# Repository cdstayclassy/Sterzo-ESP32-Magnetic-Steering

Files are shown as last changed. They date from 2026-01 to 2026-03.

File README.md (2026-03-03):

# Build your own bike trainer steering device with an ESP32 and AS5600 magnetic sensor!

A DIY bike trainer for apps such as Zwift or GTBikeV, similar to the Sterzo steering device. This project, built using an ESP32 and AS5600 magnetic rotary position sensor using the Sterzo protocol, allows you to add realistic steering control to your indoor cycling experience using a rotating handlebar mechanism with magnetic angle detection.

## Features

- Smooth, continuous steering control using magnetic rotary position sensor
- Bluetooth Low Energy (BLE) communication with Zwift and GTBikeV
- Auto-calibration at startup
- Handlebar-mounted recenter button for mid-ride calibration
- ±40° steering range (Zwift standard)
- Configurable dead zone for easier straight-line riding
- Adjustable sensitivity and update rate
- LED status indicator with error codes for easy troubleshooting
- All settings easily configurable at top of code file
- **Steering Overlay** — floating Python app showing live angle via BLE or USB serial

## Hardware Required

**Required:**
- **ESP32 Development Board** (any variant with I2C support)
- **AS5600 Magnetic Rotary Position Sensor** - 12-bit contactless angle measurement
- **Diametrically magnetized magnet** (typically included with AS5600 or purchase separately)
  - Recommended: 6mm diameter x 3mm thickness
- **Mounting mechanism** for handlebar rotation (DIY - see below)
- **Jumper wires** - for connections
- **USB cable** - for power and programming

**Optional:**
- **3-5mm LED and 220Ω resistor** (any color) - for status indication
- **Momentary push button** - for recenter function

## Wiring Connections

### AS5600 Sensor

| AS5600 Pin | ESP32 Pin | Description |
|---|---|---|
| VCC | 3.3V | Power supply (use 3.3V, NOT 5V) |
| GND | GND | Ground |
| SDA | GPIO 21 | I2C Data |
| SCL | GPIO 20 | I2C Clock (compatible with ESP32 Mini) |

### External LED - OPTIONAL (Status Indicator)

| LED Connection | ESP32 Pin | Description |
|---|---|---|
| LED Anode (+, long leg) | GPIO 2 | Via 220Ω resistor |
| LED Cathode (-, short leg) | GND | Ground |

### Recenter Button - OPTIONAL

| Button Connection | ESP32 Pin | Description |
|---|---|---|
| One leg | GPIO 4 | No resistor needed |
| Other leg | GND | Ground |

### Quick Wiring Summary

```
AS5600 SDA  → ESP32 GPIO 21
AS5600 SCL  → ESP32 GPIO 20
AS5600 VCC  → ESP32 3.3V
AS5600 GND  → ESP32 GND

LED (+)     → 220Ω resistor → ESP32 GPIO 2  (OPTIONAL)
LED (-)     → ESP32 GND

Button      → ESP32 GPIO 4 and GND          (OPTIONAL)
```

**For detailed wiring diagrams and step-by-step instructions, see [WIRING_GUIDE.md](WIRING_GUIDE.md)**

**Magnet placement**: Position the diametrically magnetized magnet 2-3mm directly above the AS5600 chip, centered on the sensor. The magnet should rotate freely with your steering mechanism.

## Software Setup

### Required Libraries

Install the following libraries through Arduino IDE Library Manager:

1. **ESP32 Board Support** - Install via Board Manager
2. **AS5600 by Rob Tillaart** - For magnetic sensor communication

### Installation Steps

1. Clone or download this repository
2. Open `Sterzo-ESP32-Magnetic-Steering.ino` in Arduino IDE
3. Install required libraries (see above)
4. Select your ESP32 board from Tools > Board
5. Select the correct COM port from Tools > Port
6. Upload the sketch to your ESP32

## Usage

1. **Initial Calibration**: Power on the ESP32 with your steering mechanism in the **center position**. The device will automatically calibrate this as the center point.
2. **Pairing with Zwift**:
   - Open Zwift on your device
   - Go to Settings > Connections
   - Look for your device name (default: "ESP32 Steering") in the Controllable devices
   - Pair the device
3. **Steering**: Rotate your handlebars left/right to steer in Zwift
4. **Recentering** (if button installed): If the base gets bumped during a ride, center your handlebars and press the recenter button. LED will flash twice to confirm.

## Steering Overlay

The `Steering Overlay/` folder contains a Python app that shows a floating, always-on-top window with a live steering arc indicator while you ride. It supports two connection modes:

| Mode | When to use |
|---|---|
| **BLE** | Standalone testing — connects directly to the ESP32 over Bluetooth |
| **USB Serial** | In-game with GTBikeV — reads angle over USB cable, leaving BLE free for the game |

### Prerequisites

- Python 3.9+
- Install dependencies:

```bash
pip install bleak pyserial
```

### Running

```bash
python3 "Steering Overlay/overlay.py"
```

The overlay opens immediately. Use the **Via:** dropdown to choose your connection:

- **BLE — Bluetooth (testing only)** — scans for the ESP32 by name/UUID and connects
- **`/dev/cu.usbmodem…` — USB JTAG/serial debug unit** (or similar) — reads angle from the USB serial port

Hit **↺** to refresh the port list if you plug in after launching.

### UI Walkthrough

```
┌─ Steering Angle  [BLE]              ✕ ─┐
│                                         │
│          -40°    0°    +40°             │
│            ╲     |     ╱               │
│             ╲    │    ╱                │
│              ────●────                  │
│                                         │
│              +12.4°                     │
│                                         │
│  ● Connected                            │
│  Via: [BLE — Bluetooth (testing only) ▾]│
└─────────────────────────────────────────┘
```

| Element | Description |
|---|---|
| **Arc track** | Gray arc spanning the full ±40° steering range |
| **Blue fill arc** | Grows from centre toward the current angle |
| **Needle** | White line from pivot to arc edge showing exact angle |
| **Angle readout** | Large numeric display (e.g. `+12.4°`) |
| **Status dot** | Green = connected, Yellow = scanning/connecting, Red = disconnected |
| **Via: dropdown** | Choose BLE or a USB serial port; switches live without restarting |
| **↺ button** | Rescans available serial ports |
| **✕ button** | Closes the overlay |

The window is **draggable** — click and drag anywhere to reposition it.

### Always-on-top & full-screen caveat (macOS)

The overlay uses `topmost` mode, which keeps it above normal windows. However, macOS full-screen apps run in their own Space, so the overlay will **not** appear on top of GTBikeV if it is in full-screen mode. Use GTBikeV in **windowed** mode, or resize it to leave a small area where the overlay can sit.

### Auto-reconnect

Both modes reconnect automatically if the connection is lost:
- **BLE**: re-scans every 3 seconds until the ESP32 is found again
- **USB Serial**: re-opens the port every 3 seconds until the device reappears

Switching the **Via:** dropdown triggers an immediate reconnect in the new mode.

### USB Serial — ESP32 board setting

The USB serial mode requires `Serial.print()` output to be routed through the USB port. On **ESP32-S3 and ESP32-C3** boards with built-in USB (no separate USB-UART chip), you must enable this in Arduino IDE before flashing:

> **Tools → USB CDC On Boot → Enabled**

Without this, `Serial` output goes to the hardware UART0 pins instead of the USB port and the overlay will not receive data. ESP32 boards with a separate USB-UART chip (CP2102, CH340, FTDI) do not need this change.

## LED Status

**Normal operation:**
- **Slow blink (1 second)**: Device ready, waiting for connection
- **Fast blink (0.5 seconds)**: Connected to Zwift/GTBikeV
- **2 quick flashes**: Recenter button pressed - new center position set

**Error codes:**
- **3 fast flashes, then pause**: Sensor not found - check I2C wiring
- **4 fast flashes, then pause**: Magnet not detected - check magnet placement

## Configuration

All settings are located at the top of `Sterzo-ESP32-Magnetic-Steering.ino` for easy customization:

```cpp
// Pin definitions
#define EXTERNAL_LED_PIN 2   // GPIO for status LED
#define CENTER_BUTTON_PIN 4  // GPIO for recenter button
#define I2C_SDA_PIN 21       // GPIO for I2C SDA (AS5600 data)
#define I2C_SCL_PIN 20       // GPIO for I2C SCL (AS5600 clock)

// LED configuration
#define LED_ACTIVE_LOW false // Set to true for ESP32-C3 onboard LED (inverts HIGH/LOW logic)

// Device configuration
#define BLE_DEVICE_NAME "ESP32 Steering"  // Bluetooth device name shown to apps

// Steering configuration
#define STEERING_DEAD_ZONE 1.0      // Degrees from center that count as "straight"
#define STEERING_SENSITIVITY 768.0  // Raw sensor units for full steering range
#define STEERING_UPDATE_MS 60       // Milliseconds between BLE updates
```

### Settings explained:

| Setting | Description | Adjust if... |
|---|---|---|
| `EXTERNAL_LED_PIN` | GPIO pin for status LED | Using a different pin |
| `CENTER_BUTTON_PIN` | GPIO pin for recenter button | Using a different pin |
| `I2C_SDA_PIN` | GPIO pin for AS5600 I2C data | Using a different pin |
| `I2C_SCL_PIN` | GPIO pin for AS5600 I2C clock | Using a different pin (default 20 for ESP32 Mini compatibility) |
| `LED_ACTIVE_LOW` | Inverts LED HIGH/LOW logic | Using an ESP32-C3 Super Mini (onboard LED is active-low) |
| `BLE_DEVICE_NAME` | Name shown in Zwift/GTBikeV pairing | You want a custom name |
| `STEERING_DEAD_ZONE` | Degrees near center that report as straight | Hard to ride straight (increase) or feels unresponsive (decrease) |
| `STEERING_SENSITIVITY` | How much physical rotation for full steering | Too twitchy (increase) or too sluggish (decrease) |
| `STEERING_UPDATE_MS` | How often steering data is sent | Laggy response (decrease) or connection issues (increase) |

### Sensitivity examples:
- `512` = ~45° physical rotation for full ±40° steering (very sensitive)
- `768` = ~68° physical rotation for full ±40° steering (moderate)
- `1024` = ~90° physical rotation for full ±40° steering (less sensitive)

### Update rate examples:
- `50` = 20 updates/sec (very responsive)
- `60` = ~17 updates/sec (smooth)
- `100` = 10 updates/sec (responsive)
- `1000` = 1 update/sec (laggy)

## Troubleshooting

**AS5600 sensor not detected:**
- Check I2C wiring connections (SDA to GPIO 21, SCL to GPIO 20)
- Verify the sensor has power (3.3V)
- Ensure magnet is positioned 2-3mm above the sensor
- Check Serial Monitor for error messages

**Steering not responding in Zwift:**
- Ensure device is paired in Zwift Connections
- Check that LED is blinking fast (connected state)
- Verify center calibration by restarting with handlebars centered

**Erratic steering behavior:**
- Check magnet alignment and distance from sensor
- Ensure magnet is diametrically magnetized
- Try adjusting sensitivity setting
- Verify no other magnets are nearby interfering with sensor

## 3D Printable Enclosure

A fully parametric 3D printable enclosure is included in the [`3d Model/`](3d%20Model/) folder. The design features:

- **Base unit** housing the ESP32 and AS5600 sensor
- **Rotating top** with wheel cradle that spins on skateboard bearings
- **Magnetic sensing** via a magnet in the rotating top passing over the fixed sensor
- Pre-rendered STL files ready to print, or customize using OpenSCAD

**Included parts:**
| File | Description |
|---|---|
| `Steering Controller Base.stl` | Main enclosure with sensor and ESP32 pockets |
| `Steering Controller Door.stl` | Removable cover for ESP32 access |
| `Steering Controller Rotating Top.stl` | Wheel cradle with bearing mounts |
| `Steering Controller Bearing Rod.stl` | Retention rods for bearings (print 4x) |
| `Steering Controller Rubber Foot.stl` | Optional grip foot (print 4x in TPU) |

**Fit test pieces** are also included to verify clearances before printing full parts.

See the [3D Model README](3d%20Model/README.md) for detailed instructions, parameters, and printing tips.

## How It Works

The AS5600 sensor uses a magnet's magnetic field to determine angular position with 12-bit resolution (0-4095 counts = 0-360°). The ESP32:

1. Reads the raw angle from the AS5600 via I2C
2. Calculates the difference from the calibrated center position
3. Handles wraparound for seamless 360° operation
4. Maps the physical rotation to Zwift's ±40° steering range
5. Sends steering data via BLE using the Sterzo protocol

## Technical Details

- **BLE Service UUID**: `347b0001-7635-408b-8918-8ff3949ce592`
- **Steering angle characteristic**: `347b0030-7635-408b-8918-8ff3949ce592`
- **Update rate**: Configurable (default: ~17 Hz / 60ms)
- **Steering range**: ±40° (Zwift standard)
- **Sensor resolution**: 0.087° (12-bit, 4096 positions)

## Issues & Contributions

Feel free to raise an issue if you encounter problems or have suggestions for improvements!

## Acknowledgments

- **Original ESP32 Sterzo code** by [stefaandesmet2003](https://github.com/stefaandesmet2003/ESP32Sterzo) ([YouTube video](https://youtu.be/6pxeI_YN5Yk)) - BLE steering protocol implementation that this project was forked from, converted from touch buttons to AS5600 magnetic sensor
- **3D enclosure inspiration** from [ESP32 Sterzo Steering Simulator](https://www.thingiverse.com/thing:4239532) by dattepp on Thingiverse

## License

This project is licensed under [CC BY-NC-SA 4.0](LICENSE) - you are free to use, share, and adapt for personal, non-commercial purposes. See the LICENSE file for details.

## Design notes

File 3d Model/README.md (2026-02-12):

# Steering Controller 3D Model

A fully parametric OpenSCAD enclosure for the ESP32 Sterzo steering controller. This design houses an ESP32 microcontroller and AS5600 magnetic rotation sensor to detect steering input from a bicycle wheel.

## Pre-Rendered STL Files

Ready-to-print STL files are included with default settings optimized for 608 skateboard bearings, standard ESP32 dev boards, and AS5600 sensor modules:

| File | Description | Quantity |
|---|---|---|
| `Steering Controller Base.stl` | Main enclosure with sensor pocket and ESP32 cavity | 1 |
| `Steering Controller Door.stl` | Removable bottom cover for ESP32 access | 1 |
| `Steering Controller Rotating Top.stl` | Wheel cradle with bearing mounts and magnet holder | 1 |
| `Steering Controller Bearing Rod.stl` | Retention rods that secure bearings in place | 4 |
| `Steering Controller Rubber Foot.stl` | Single grip foot with textured bottom (print in TPU, one at a time) | 4 |
| `Fit Test - AS5600 Sensor.stl` | Test piece to verify sensor pocket fit | 1 |
| `Fit Test - 608 Bearing.stl` | Test piece to verify bearing pocket and rod fit | 1 |

**Recommended print order:** Fit test pieces first, then base, door, top, bearing rods, and optionally feet.

## Parts Overview

The model generates several printable parts controlled by the `render_part` parameter:

| Value | Part | Description |
|---|---|---|
| 0 | Base | Main enclosure with sensor pocket, ESP32 cavity, and cable holes |
| 1 | Door | Removable cover for the ESP32 pocket (bottom access) |
| 2 | Top | Rotating wheel cradle with magnet holder and bearing mounts |
| 3 | All Preview | Assembly view showing all parts together (not for printing) |
| 4 | Bearing Rod | Small rods that secure bearings in place |
| 5 | AS5600 Fit Test | Small test piece to verify sensor pocket and peg fit |
| 6 | Bearing Fit Test | Small test piece to verify bearing pocket and rod fit |
| 7 | Rubber Foot | Single printable grip foot with textured bottom (print in TPU, one at a time) |

## How It Works

1. The **base** sits stationary and contains the AS5600 sensor at its center post
2. The **rotating top** holds your bike wheel and spins freely on the base
3. A magnet in the top passes over the AS5600 sensor, which detects the rotation angle
4. Bearings mounted in the top ride on the base's outer rim for smooth rotation
5. The ESP32 reads the sensor data and transmits steering input via Bluetooth

## Key Parameters

### Main Dimensions
- `base_diameter` - Overall diameter of the enclosure (default: 120mm)
- `base_height` - Height of the base platform (default: 22mm)
- `center_diameter` - Diameter of the raised center post (default: 65mm)
- `center_height` - Additional height of center post above base (default: 10mm)

### AS5600 Sensor Pocket
- `as5600_width` / `as5600_depth` - Actual measured board dimensions
- `as5600_pocket_clearance` - Extra space added to pocket (default: 0.8mm)
- `as5600_ledge_depth` - How deep the board sits from the top
- `as5600_peg_diameter` - Diameter of mounting pegs (set smaller than board holes for fit)
- `as5600_peg_height` / `as5600_peg_spacing_*` - Peg configuration

### ESP32 Pocket
- `esp32_width` / `esp32_depth` - Cavity dimensions
- `esp32_pocket_height` - Depth of the pocket from bottom
- `esp32_offset_y` - Offset from center if needed

### Rotating Top
- `top_height` - Total height of the rotating section (default: 62mm)
- `top_wall_thickness` - Thickness of the wheel cradle walls (default: 18mm)
- `wheel1_width` - Primary wheel slot width (default: 30mm)
- `wheel1_depth_front` / `wheel1_depth_back` - Front and back slot depths (default: 30mm each)
- `wheel2_width` - Secondary wheel slot width (default: 50mm)
- `wheel2_depth_left` / `wheel2_depth_right` - Left and right slot depths (default: 30mm each)
- `wheel2_enabled` - Enable perpendicular wheel slots for different wheel sizes

### Bearings
- `bearings_enabled` - Toggle bearing system on/off
- `bearing_count` - Number of bearings (3, 4, or 5)
- `bearing_radius` - Distance from center to bearing position (default: 47mm)
- `bearing_od` / `bearing_id` / `bearing_thickness` - Bearing dimensions (default: 608 skateboard bearings, 22/8/7mm)
- `bearing_pocket_clearance` - Extra space around bearing for free spinning (default: 2.5mm)
- `bearing_stickout` - How far bearings extend below top piece (default: 2.2mm, directly affects magnet gap!)
- `bearing_rod_diameter` - Diameter of retention rods (default: 7.9mm for snug fit in 8mm bearing ID)
- `bearing_rod_length` - Length of rod spanning across bearing (default: 20mm)
- `bearing_rod_clearance` - Extra space around rod in slot (default: 0.3mm)

### Magnet and Sensor Gap

The AS5600 magnetic rotation sensor works best with a 2-3mm air gap between the magnet and the sensor chip.

**Understanding the geometry:**
- The bearings mounted in the top piece ride on the base's outer rim
- How far the bearings stick out below the top determines how high the top sits
- **Actual magnet-sensor gap** = `bearing_stickout` + `magnet_air_gap`

**Example with defaults:**
- bearing_stickout = 2.2mm
- magnet_air_gap = 0mm
- **Total gap = 2.2mm** (within optimal 2-3mm range)

**Parameters:**
- `bearing_stickout` - How far bearings extend below top (set to desired gap if magnet_air_gap=0)
- `magnet_diameter` / `magnet_height` - Magnet dimensions
- `magnet_air_gap` - Additional gap beyond bearing stickout (set to 0 if stickout provides adequate gap)

**Tip:** OpenSCAD will echo the actual magnet gap when you render. Check the console output for: `MAGNET GAP: bearing_stickout=Xmm + air_gap=Ymm = Zmm total`

### Optional Features
- `rubber_feet_enabled` - Add recesses for rubber feet
- `rubber_foot_diameter` / `rubber_foot_depth` - Recess dimensions
- `rubber_foot_height` - Height of printable feet (for TPU printing)
- `usb_enabled` - USB-C cable passthrough hole
- `led_enabled` - Status LED hole with stepped diameter

### Compensating for Bike Head Tube Angle

If your bike's head tube angle causes the wheel to contact one side of the cradle lower than the other (uneven pressure on front vs back cutouts), you can adjust the wheel slot depths independently:

**For wheel position 1 (front/back cutouts):**
- If the wheel contacts the **front** lower, increase `wheel1_depth_front`
- If the wheel contacts the **back** lower, increase `wheel1_depth_back`

**For wheel position 2 (left/right cutouts):**
- Adjust `wheel2_depth_left` or `wheel2_depth_right` as needed

**Example:** A road bike with a 73° head tube angle might need 3-5mm extra depth on the front cutout:
```
wheel1_depth_front = 33;  // 3mm deeper than default
wheel1_depth_back = 30;   // normal
```

This allows the wheel to sit evenly in the cradle without tilting the entire base.

## Fit Testing (Recommended)

Before printing the full parts, use the fit test pieces to verify your clearance settings work with your printer:

1. **AS5600 Fit Test** (render_part = 5)
   - Print this small piece first
   - Test that your AS5600 board drops into the pocket easily
   - Verify the mounting pegs align with the board holes
   - Adjust `as5600_pocket_clearance` (larger = looser pocket) and `as5600_peg_diameter` (smaller = thinner pegs) as needed

2. **Bearing Fit Test** (render_part = 6)
   - Print this small piece to test bearing fit
   - Verify bearings slide into the pocket smoothly
   - Test that the rod fits into the cross slot
   - Adjust `bearing_pocket_clearance` and `bearing_rod_clearance` as needed

This saves significant time and filament compared to reprinting the full base or top.

## Printing Tips

- **Base**: Print with the flat bottom on the bed. Supports are needed inside the ESP32 pocket cavity (the ceiling spans 60mm+ and won't bridge cleanly). Surface quality in the pocket doesn't matter since the door covers it.
- **Door**: Print flat, countersunk screw holes face up
- **Top**: Print right-side up (bottom on bed). The center recess ceiling (~61mm ring with center hole) may need supports or can bridge on most printers. This is easier than printing upside down, which would require supporting the entire solid floor section.
- **Bearing Rod**: Print standing vertically for strength
- **Rubber Foot**: Print in TPU/flexible filament for best grip. Print one at a time to reduce stringing. Already oriented with textured surface on top (becomes the grip surface when installed). The textured nubs provide traction on smooth surfaces. Print 4 copies.

Recommended settings:
- Layer height: 0.2mm
- Infill: 20-30%
- Walls: 3-4 perimeters
- Material: PLA or PETG

## Hardware Required

- 1x ESP32 development board
- 1x AS5600 magnetic rotation sensor module (23mm x 23mm typical)
- 1x Diametrically magnetized magnet (default: 3mm diameter x 2mm height)
- 4x 608 skateboard bearings (22mm OD x 8mm ID x 7mm thick)
- 4x M2 screws for door (or M2.5/M3, selectable via `door_screw_size`)
- 4x Rubber feet (optional) - either adhesive feet or print your own in TPU using render_part = 7
- 1x 3mm LED (optional)

## Customization

Open `Steering Controller.scad` in OpenSCAD and use the Customizer panel (View > Hide Customizer to toggle) to adjust all parameters. Parameters are organized into logical groups in the right panel.

**Important**: If bearings are cutting through the outer wall, reduce `bearing_radius` to move them inward. The bearing pockets extend `bearing_od/2` beyond the bearing_radius position.

## License

This project is licensed under [CC BY-NC-SA 4.0](../LICENSE) - free for personal use, no commercial use permitted.

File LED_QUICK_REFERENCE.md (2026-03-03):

# External LED - Quick Reference

## Hardware Hookup

### What You Need
- 3mm LED (any color - red, green, blue, yellow, etc.)
- 220Ω resistor (red-red-brown or red-red-black-black-brown)
- 2x jumper wires

### Wiring (Simple!)

```
ESP32 GPIO 2 ──[220Ω resistor]──►|──── ESP32 GND
                                LED
```

**Step-by-step:**
1. LED long leg (+) → one end of 220Ω resistor
2. Other end of resistor → ESP32 GPIO 2
3. LED short leg (-) → ESP32 GND

### Pin Location

**GPIO 2** is located on your ESP32 board - check the pinout for your specific model:
- Usually labeled "GPIO2", "D2", or "IO2"
- Common ESP32 Dev boards have it near the top

**GND** - Any ground pin on the ESP32

## Code Support

✅ **The code already supports this!**

The LED functionality is built into `Sterzo-ESP32-Magnetic-Steering.ino`:
- `#define EXTERNAL_LED_PIN 2` - Pin definition
- `#define LED_ACTIVE_LOW false` - Set to `true` for ESP32-C3 Super Mini (onboard LED is active-low)
- `LED_ON` / `LED_OFF` macros automatically handle inverted logic when `LED_ACTIVE_LOW` is enabled

**No code changes needed** - just wire it up and upload!

### ESP32-C3 Super Mini Users

If you are using an **ESP32-C3 Super Mini**, the onboard LED uses active-low logic (LOW = on, HIGH = off). Change this line in `Sterzo-ESP32-Magnetic-Steering.ino`:
```cpp
#define LED_ACTIVE_LOW true  // Set to true for ESP32-C3 onboard LED
```

## LED Status Meanings

### Normal Operation

| Blink Pattern | Meaning |
|---|---|
| Slow blink (1 sec on/off) | Ready, waiting for Zwift/GTBikeV connection |
| Fast blink (0.5 sec on/off) | Connected to Zwift/GTBikeV! |
| Solid on | Booting up |
| Off | Not powered or code issue |

### Error Codes

| Flash Pattern | Meaning | Fix |
|---|---|-----|
| 3 fast flashes, pause, repeat | Sensor not found | Check I2C wiring (SDA→GPIO21, SCL→GPIO20) |
| 4 fast flashes, pause, repeat | Magnet not detected | Check magnet placement over sensor |

**Error flash timing:** 100ms on, 100ms off for each flash, then 1.5 second pause before repeating.

## Testing

1. Upload `Sterzo-ESP32-Magnetic-Steering.ino` to ESP32
2. Connect LED as shown above
3. LED should turn on solid for ~2 seconds during boot
4. If sensor/magnet OK → slow blinking (waiting for connection)
5. If error → 3 or 4 fast flashes repeating (see Error Codes above)
6. When you pair with Zwift/GTBikeV → fast blinking!

## Troubleshooting

### LED doesn't turn on at all
- ❌ Check polarity: Long leg to resistor, short leg to GND
- ❌ Check resistor is connected
- ❌ Verify GPIO 2 is connected
- ❌ Try a different LED (might be dead)

### LED very dim
- Resistor too high - try 150Ω instead
- Wrong LED type - use standard 3mm LED

### LED too bright or gets warm
- ⚠️ Resistor too low or missing - **MUST** use 220Ω minimum
- Never connect LED directly to GPIO without resistor!

### Built-in LED works but external doesn't
- Check GPIO 2 connection
- Try different GPIO pin and update code (line 22)

## Alternative Pins

Don't like GPIO 2? You can use these instead:

**Safe alternatives:** GPIO 4, 5, 12, 13, 14, 15, 16, 17, 18, 19, 22, 23, 25, 26, 27, 32, 33

**Change in code:**
Edit line 22 in `Sterzo-ESP32-Magnetic-Steering.ino`:
```cpp
#define EXTERNAL_LED_PIN 2  // Change to your desired pin
```

**Don't use:** GPIO 20, 21 (I2C), GPIO 0, 1, 3 (boot/serial)

## Resistor Value Guide

| Resistor | Brightness | Notes |
|---|---|---|
| 100Ω | Very bright | May damage LED over time |
| 150Ω | Bright | Good for dim environments |
| **220Ω** | **Normal** | **Recommended** |
| 330Ω | Dimmer | Good for bright environments |
| 470Ω | Very dim | Hard to see in daylight |

## Multiple LEDs?

Want red for disconnected, green for connected?

**You'll need to modify the code** - but it's easy:

1. Add second LED definition:
```cpp
#define DISCONNECTED_LED_PIN 2  // Red LED
#define CONNECTED_LED_PIN 4     // Green LED
```

2. In setup(), initialize both:
```cpp
pinMode(DISCONNECTED_LED_PIN, OUTPUT);
pinMode(CONNECTED_LED_PIN, OUTPUT);
```

3. In loop(), control separately:
```cpp
if (deviceConnected) {
  digitalWrite(CONNECTED_LED_PIN, ledState);    // Blink green
  digitalWrite(DISCONNECTED_LED_PIN, LOW);      // Red off
} else {
  digitalWrite(DISCONNECTED_LED_PIN, ledState); // Blink red
  digitalWrite(CONNECTED_LED_PIN, LOW);         // Green off
}
```

Wire each LED with its own 220Ω resistor to different GPIO pins!

## Why 220Ω?

ESP32 GPIO pins output 3.3V and can safely provide ~40mA max (20mA recommended).

**Math:**
- LED forward voltage: ~2V (typical red LED)
- Remaining voltage: 3.3V - 2V = 1.3V
- Desired current: 5-10mA (safe for LED and ESP32)
- Resistor needed: 1.3V ÷ 0.01A = 130Ω minimum

**220Ω gives:** 1.3V ÷ 220Ω = 5.9mA (safe, bright enough)

## Quick Checks ✓

Before powering on:
- [ ] 220Ω resistor in series with LED
- [ ] LED polarity correct (long leg to GPIO 2)
- [ ] All connections secure
- [ ] No exposed wires touching each other
- [ ] Code uploaded to ESP32

Power on and enjoy your status LED! 💡

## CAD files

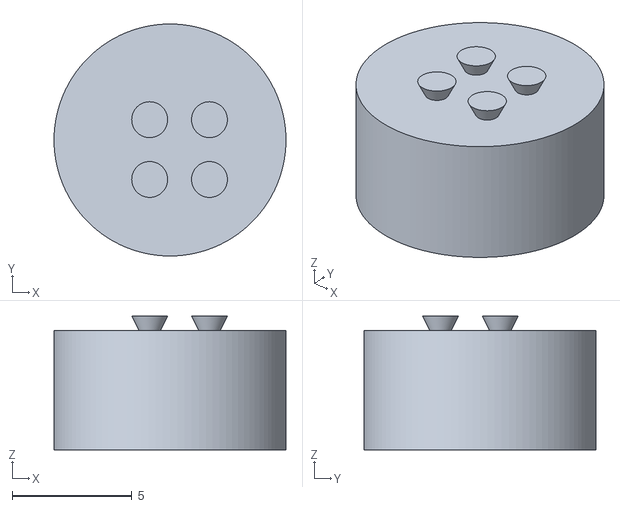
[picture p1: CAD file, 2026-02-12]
3d Model/Rendered with defaults/Steering Controller PETG Feet.stl
9.70 x 9.70 x 5.59

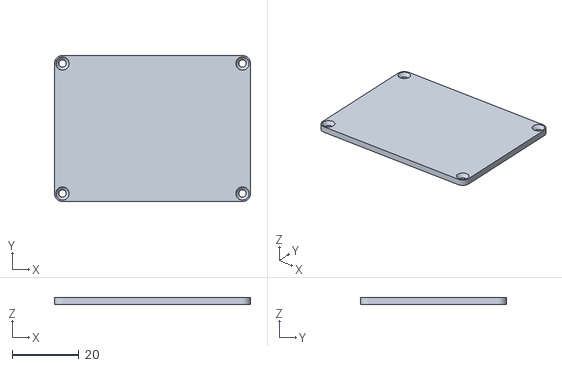
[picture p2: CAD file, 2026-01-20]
3d Model/Rendered with defaults/Steering Controller Door.stl
58.8 x 43.8 x 2.00

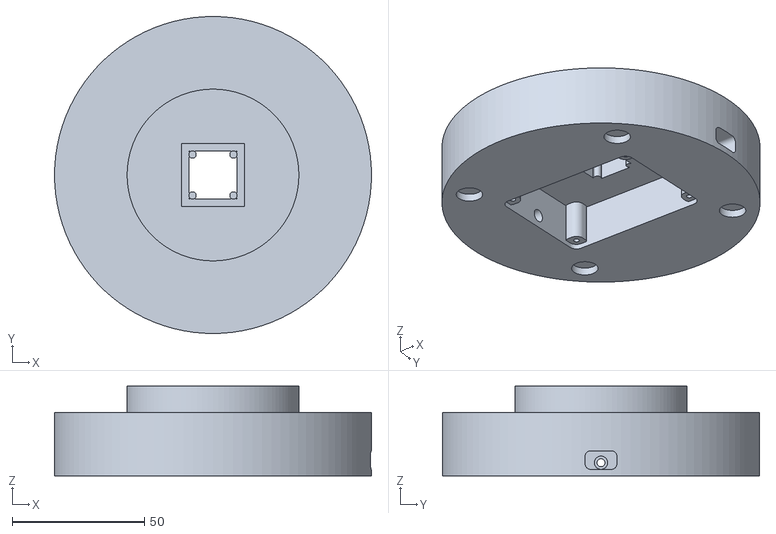
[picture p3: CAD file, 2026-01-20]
3d Model/Rendered with defaults/Steering Controller Base.stl
120.0 x 120.0 x 34.0

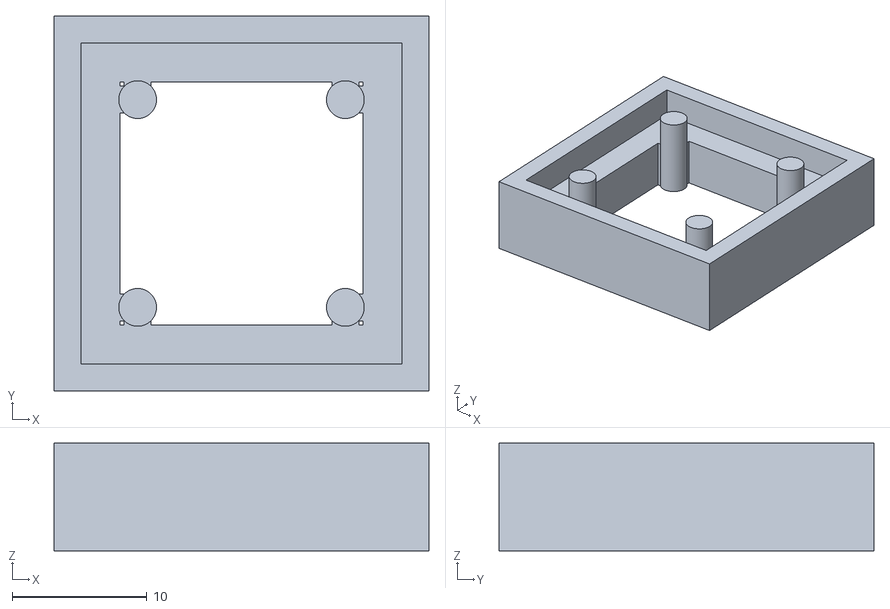
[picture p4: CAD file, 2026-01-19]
3d Model/Rendered with defaults/Fit Test - AS5600 Sensor.stl
27.8 x 27.8 x 8.00

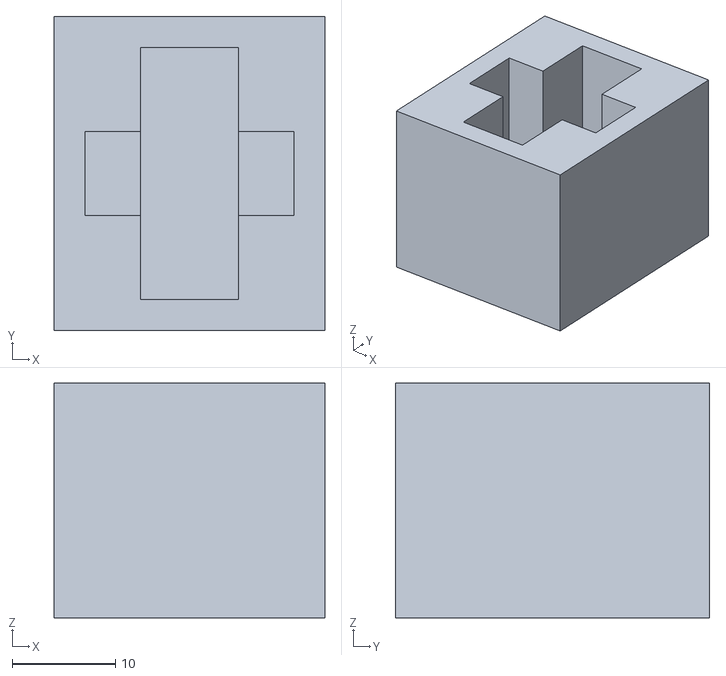
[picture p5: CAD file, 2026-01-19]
3d Model/Rendered with defaults/Fit Test - 608 Bearing.stl
26.3 x 30.5 x 22.8

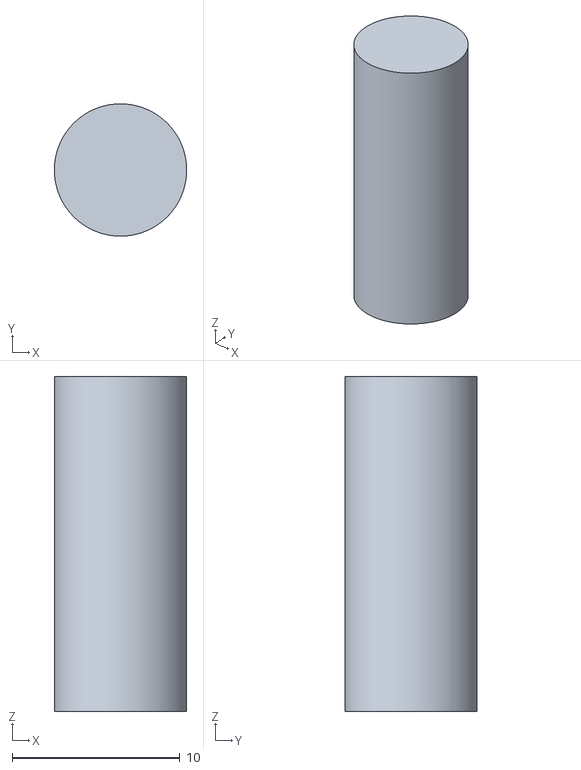
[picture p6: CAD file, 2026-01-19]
3d Model/Rendered with defaults/Steering Controller Bearing Rod.stl
7.90 x 7.90 x 20.0

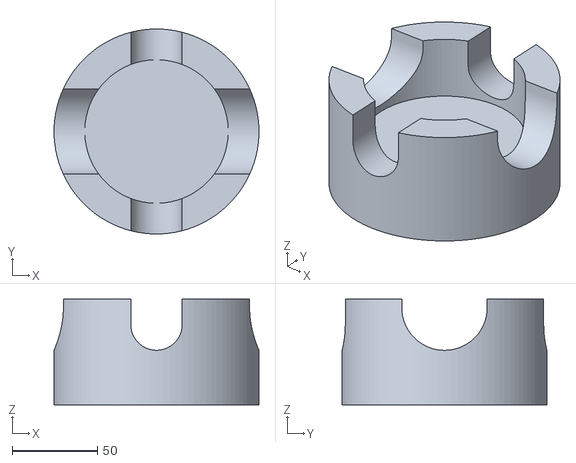
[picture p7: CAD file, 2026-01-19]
3d Model/Rendered with defaults/Steering Controller Rotating Top.stl
120.0 x 120.0 x 62.0

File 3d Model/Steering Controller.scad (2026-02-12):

// ESP32 Sterzo Enclosure Base
// Round base with raised center for AS5600 sensor
// Parametric design with rubber feet, USB-C hole, and LED hole

/* [Main Dimensions] */
// Base diameter
base_diameter = 120;
// Base height (not including center post)
base_height = 24;
// Center post diameter
center_diameter = 65;
// Center post additional height
center_height = 10;
// Total height = base_height + center_height = 23mm

/* [AS5600 Sensor Pocket] */
// AS5600 board width (enter actual measured width)
as5600_width = 23;
// AS5600 board depth (enter actual measured depth)
as5600_depth = 23;
// Pocket clearance (extra space added to width and depth for fit)
as5600_pocket_clearance = 0.8;
// AS5600 ledge depth (board sits on this ledge, recessed from top)
as5600_ledge_depth = 3;
// Opening below AS5600 (for wires from ESP32) - goes through to ESP32 pocket
as5600_opening_width = 18;
as5600_opening_depth = 18;

/* [AS5600 Mounting Pegs] */
// Enable mounting pegs (for clip-in mounting)
as5600_peg_enabled = true;
// Peg diameter (set smaller than board hole for fit, e.g. 2.8 for 3mm holes)
as5600_peg_diameter = 2.8; // [1:0.1:5]
// Peg height above pocket floor (negative = recessed below floor)
as5600_peg_height = 3; // [-5:0.1:10]
// Peg spacing X (distance between peg centers, left to right)
as5600_peg_spacing_x = 15.5; // [1:0.1:30]
// Peg spacing Y (distance between peg centers, front to back)
as5600_peg_spacing_y = 15.5; // [1:0.1:30]

/* [ESP32 Pocket (Bottom)] */
// ESP32 pocket enabled
esp32_enabled = true;
// ESP32 pocket width
esp32_width = 60;
// ESP32 pocket depth
esp32_depth = 45;
// ESP32 pocket height (from bottom)
esp32_pocket_height = 17;
// ESP32 pocket offset from center (0 = centered below AS5600 opening)
esp32_offset_y = 0;

/* [ESP32 Door] */
// Door thickness
door_thickness = 2;
// Door clearance (gap between door and pocket walls)
door_clearance = 0.6;
// Door corner radius (should match pocket)
door_corner_radius = 3;
// Screw size (0=M2, 1=M2.5, 2=M3)
door_screw_size = 0; // [0:M2, 1:M2.5, 2:M3]
// Mounting post diameter (should be larger than screw hole)
door_post_diameter = 6;
// Mounting post height (from door surface into pocket)
door_post_height = 8;
// Screw hole depth in post
door_screw_depth = 6;

// Screw dimensions lookup tables (hole diameter, head diameter, countersink depth)
// M2: 2.2mm hole, 4mm head, 1.2mm countersink
// M2.5: 2.7mm hole, 5mm head, 1.5mm countersink
// M3: 3.2mm hole, 6mm head, 1.8mm countersink
door_screw_diameter = (door_screw_size == 0) ? 2.2 : (door_screw_size == 1) ? 2.7 : 3.2;
door_screw_head_diameter = (door_screw_size == 0) ? 4 : (door_screw_size == 1) ? 5 : 6;
door_countersink_depth = (door_screw_size == 0) ? 1.2 : (door_screw_size == 1) ? 1.5 : 1.8;

/* [Rubber Feet] */
// Enable rubber feet recesses
rubber_feet_enabled = true;
// Rubber foot diameter
rubber_foot_diameter = 10;
// Rubber foot recess depth (how deep the foot sits in the base)
rubber_foot_depth = 3;
// Rubber foot total height (for printable feet)
rubber_foot_height = 5; // [1:0.5:10]
// Rubber foot clearance (subtracted from diameter for fit)
rubber_foot_clearance = 0.3;
// Rubber foot distance from center
rubber_foot_radius = 50;
// Number of rubber feet
rubber_foot_count = 4;

/* [USB-C Hole] */
// Enable USB-C cable hole
usb_enabled = true;
// USB-C hole width
usb_width = 7;
// USB-C hole height
usb_height = 12;
// USB-C hole center height from bottom (outside)
usb_center_height = 6;
// USB-C hole angular position (degrees, 0 = front)
usb_angle = 0;

/* [LED Hole] */
// Enable LED hole
led_enabled = true;
// LED lens diameter (front opening)
led_lens_diameter = 3;
// LED body diameter (back opening for wires)
led_body_diameter = 5;
// LED lens depth (how far the 3mm section extends)
led_lens_depth = 2;
// LED hole center height from bottom (outside)
led_center_height = 5;
// LED hole angular position (degrees, 180 = opposite USB)
led_angle = 180;

/* [Button Hole] */
// Enable button/reset hole
button_enabled = false;
// Button shaft hole diameter (threaded part that goes through wall)
button_diameter = 7; // [5:1:16]
// Button flange diameter (outer recess for button head - set to 0 for no recess)
button_flange_diameter = 0; // [0:1:20]
// Button flange recess depth (creates flat mounting surface on curved wall)
button_flange_depth = 2; // [1:0.5:5]
// Button hole center height from bottom (outside)
button_center_height = 8;
// Button hole angular position (degrees, 0 = USB side, 90 = right side)
button_angle = 90;

/* [Angled Base] */
// Enable angled base (tilts top surface to compensate for bike head tube angle)
tilt_enabled = false;
// Tilt angle in degrees (typical bike head tube angle offset: 5-20°)
tilt_angle_degrees = 0; // [0:1:25]
// Tilt direction (degrees: 0 = back edge high, 90 = right edge high, 180 = front edge high)
tilt_direction = 0; // [0:15:345]

/* [Rotating Top - Main] */
// Top total height
top_height = 62;
// Top wall thickness (also determines floor thickness above bearing pockets)
// Must be thick enough that bearing_pocket_depth doesn't cut through floor
top_wall_thickness = 18;
// Radial clearance between top recess and base center post (side gap)
top_recess_clearance = 1;

/* [Rotating Top - Wheel 1 (Front/Back)] */
// Wheel 1 slot width (tire width + clearance)
wheel1_width = 30;
// Wheel 1 FRONT slot depth (how far DOWN from top the cutout extends)
// Increase this if wheel contacts front lower due to bike head tube angle
wheel1_depth_front = 30;
// Wheel 1 BACK slot depth (how far DOWN from top the cutout extends)
wheel1_depth_back = 30;

/* [Rotating Top - Wheel 2 (Left/Right)] */
// Enable second wheel position (for different wheel sizes)
wheel2_enabled = true;
// Wheel 2 slot width (tire width + clearance)
wheel2_width = 50;
// Wheel 2 LEFT slot depth (how far DOWN from top the cutout extends)
wheel2_depth_left = 30;
// Wheel 2 RIGHT slot depth (how far DOWN from top the cutout extends)
wheel2_depth_right = 30;

/* [Rotating Top - Magnet] */
// Magnet diameter
magnet_diameter = 3;
// Magnet height/thickness
magnet_height = 2;
// Magnet pocket extra clearance
magnet_clearance = 0.2;
// IMPORTANT: The actual magnet-to-sensor gap = bearing_stickout + magnet_air_gap
// where bearing_stickout = bearing_od - bearing_pocket_depth (how far bearing extends below top)
// With default values: stickout = 22 - 19 = 3mm, so set air_gap = 0 for ~3mm total gap
// Air gap between magnet and center post top (add to bearing stickout for total sensor gap)
magnet_air_gap = 0;

/* [Rotating Top - Bearings] */
// Enable bearing rod slots
bearings_enabled = true;
// Number of bearings (3, 4, or 5)
bearing_count = 4; // [3, 4, 5]
// Bearing outer diameter (608 skateboard = 22mm)
bearing_od = 22;
// Bearing inner diameter (608 skateboard = 8mm)
bearing_id = 8;
// Bearing thickness (608 skateboard = 7mm)
bearing_thickness = 7;
// Bearing pocket clearance (extra space around bearing for free spinning)
bearing_pocket_clearance = 2.5; // [0:0.1:5]
// Bearing stickout (how far bearing extends below top piece - directly affects magnet gap!)
// For AS5600, aim for 2-3mm total gap. If magnet_air_gap=0, set stickout to desired gap.
bearing_stickout = 2.2; // [0:0.1:10]
// Bearing distance from center (should be in the track area)
bearing_radius = 47;
// Rod diameter for bearing retention
bearing_rod_diameter = 7.9;
// Rod clearance (extra space around rod in slot)
bearing_rod_clearance = 0.3;
// Bearing rod length (length of rod that spans across bearing)
bearing_rod_length = 20;

/* [Rendering] */
// What to render
render_part = 0; // [0:Base, 1:Door, 2:Top, 3:All Preview, 4:Bearing Rod, 5:AS5600 Fit Test, 6:Bearing Fit Test, 7:Rubber Feet]
$fn = 100;

// Calculate wall thickness at edge
wall_thickness = 2;

// ==================== DERIVED CALCULATIONS ====================
// These depend on parameters defined above

// AS5600 derived dimensions (with clearances applied)
as5600_pocket_width = as5600_width + as5600_pocket_clearance;
as5600_pocket_depth = as5600_depth + as5600_pocket_clearance;

// Bearing pocket depth: derived from stickout (how deep the pocket is in the top piece)
bearing_pocket_depth = bearing_od - bearing_stickout;

// Actual magnet-to-sensor gap (for AS5600 optimal range is 2-3mm)
// = bearing_stickout + magnet_air_gap
actual_magnet_gap = bearing_stickout + magnet_air_gap;
echo(str("MAGNET GAP: bearing_stickout=", bearing_stickout, "mm + air_gap=", magnet_air_gap, "mm = ", actual_magnet_gap, "mm total"));

// Rod ledge depth - where rod rests to achieve correct bearing stickout
// Rod center must align with bearing center for proper support
// Formula: (bearing_od/2) + (rod_diameter/2) - bearing_stickout
rod_ledge_depth = bearing_od/2 + bearing_rod_diameter/2 - bearing_stickout;
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

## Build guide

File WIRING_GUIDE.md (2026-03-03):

# ESP32 Sterzo - Wiring Guide

## Components Needed

**Required:**
- ESP32 Development Board
- AS5600 Magnetic Rotary Position Sensor Module
- 6mm diameter disc magnet (3mm thick, diametrically magnetized)
- Jumper wires
- USB-C cable (for power/programming)

**Optional:**
- 3mm LED (any color) - for status indication
- 220Ω resistor (for LED)
- Momentary push button - for recenter function (mount on handlebars)

## Complete Wiring Diagram

```
                     ESP32
                  ┌─────────┐
                  │         │
AS5600 SDA ──────►│ GPIO21  │ (I2C Data)
AS5600 SCL ──────►│ GPIO20  │ (I2C Clock)
AS5600 VCC ──────►│ 3.3V    │
AS5600 GND ──────►│ GND     │
                  │         │
LED (+) ─[220Ω]──►│ GPIO2   │ (Status LED - OPTIONAL)
LED (-) ─────────►│ GND     │
                  │         │
Button ──────────►│ GPIO4   │ (Recenter Button - OPTIONAL)
Button ──────────►│ GND     │
                  │         │
USB-C ───────────►│ USB     │ (Power/Programming)
                  └─────────┘
```

## Pin-by-Pin Connections

### AS5600 Sensor → ESP32

| AS5600 Pin | ESP32 Pin | Description |
|---|---|---|
| VCC | 3.3V | Power supply (NOT 5V!) |
| GND | GND | Ground |
| SDA | GPIO 21 | I2C Data line |
| SCL | GPIO 20 | I2C Clock line (ESP32 Mini compatible) |

**Note:** Some AS5600 modules have additional pins (DIR, PGO, OUT) - these are not used and can be left unconnected.

### External LED → ESP32 (OPTIONAL)

| LED Connection | ESP32 Pin | Notes |
|---|---|---|
| Anode (+, long leg) | 220Ω resistor → GPIO 2 | Use resistor! |
| Cathode (-, short leg) | GND | Ground |

**Important:** The 220Ω resistor is **required** to limit current and prevent damaging the LED or ESP32.

### Recenter Button → ESP32 (OPTIONAL)

| Button Connection | ESP32 Pin | Notes |
|---|---|---|
| One leg | GPIO 4 | No resistor needed (uses internal pullup) |
| Other leg | GND | Ground |

**Usage:** Press button to set current handlebar position as new center. Useful if the base gets bumped during a ride. LED will flash twice to confirm.

**Mounting tip:** Use a handlebar-mounted button for easy access while riding. Any momentary push button will work.

### Power

| Connection | ESP32 Pin | Notes |
|---|---|---|
| USB-C Cable | USB Port | Provides 5V power and programming interface |

## Step-by-Step Wiring Instructions

### 1. Power Off
- Ensure ESP32 is **NOT** connected to USB before wiring
- This prevents accidental shorts

### 2. Connect AS5600 Sensor

**a) Power connections:**
1. Connect AS5600 **VCC** to ESP32 **3.3V** (red wire recommended)
2. Connect AS5600 **GND** to ESP32 **GND** (black wire recommended)

**b) I2C connections:**
3. Connect AS5600 **SDA** to ESP32 **GPIO 21** (yellow/green wire)
4. Connect AS5600 **SCL** to ESP32 **GPIO 20** (orange/blue wire)

### 3. Connect External LED (Optional)

**a) Identify LED polarity:**
- **Anode (+)** = Long leg, goes to GPIO 2
- **Cathode (-)** = Short leg, goes to GND
- If legs are cut, look inside: smaller piece = anode

**b) Wire LED:**
1. Connect LED **anode (+)** to one end of 220Ω resistor
2. Connect other end of resistor to ESP32 **GPIO 2**
3. Connect LED **cathode (-)** to ESP32 **GND**

```
GPIO 2 ──[220Ω]──►|──── GND
                  LED
```

### 4. Connect Recenter Button (Optional)

**a) Wire button:**
1. Connect one leg of button to ESP32 **GPIO 4**
2. Connect other leg to ESP32 **GND**

```
GPIO 4 ──[Button]── GND
```

**No resistor needed** - the ESP32 uses its internal pullup resistor.

### 5. Double-Check Connections

Before powering on, verify:
- [ ] AS5600 VCC → ESP32 3.3V (NOT 5V!)
- [ ] AS5600 GND → ESP32 GND
- [ ] AS5600 SDA → ESP32 GPIO 21
- [ ] AS5600 SCL → ESP32 GPIO 20
- [ ] (If using LED) LED has 220Ω resistor in series
- [ ] (If using LED) LED polarity is correct (long leg to GPIO 2)
- [ ] (If using button) Button connected between GPIO 4 and GND
- [ ] No wires touching each other

### 6. Power On and Test

1. Connect USB-C cable to ESP32
2. Open Arduino IDE Serial Monitor (115200 baud)
3. You should see:
   ```
   Starting ESP32 Steering with AS5600!
   I2C initialized
   Checking AS5600 connection...
   AS5600 sensor detected!
   Magnet status: Detected
   ESP32 Steering ready!
   Status: OK - Sensor and magnet detected
   ```
4. If using LED: should turn on and start blinking
5. If using button: press it and LED will flash twice, Serial will show "Recentered!"

## LED Status Codes

### Normal Operation

| LED Behavior | Meaning |
|---|---|
| Slow blink (1 sec on/off) | Waiting for Zwift/GTBikeV connection |
| Fast blink (0.5 sec on/off) | Connected to Zwift/GTBikeV - ready to use! |
| 2 quick flashes | Recenter button pressed - new center set |
| Solid on | Booting up / initializing |
| Off | Not powered or code not running |

### Error Codes

| LED Behavior | Meaning | Fix |
|---|---|-----|
| 3 fast flashes, pause, repeat | Sensor not found | Check I2C wiring (SDA→GPIO21, SCL→GPIO20) |
| 4 fast flashes, pause, repeat | Magnet not detected | Check magnet placement over sensor |

## GPIO Pin Information

### Why GPIO 2?

GPIO 2 is chosen because:
- ✅ Safe to use on all ESP32 boards
- ✅ Can be used as output
- ✅ Often has built-in LED too
- ✅ Not used for I2C or other critical functions
- ✅ Accessible on most ESP32 dev boards

### Why NOT GPIO 20/21?

GPIO 20 and GPIO 21 are reserved for I2C communication with the AS5600 sensor and **cannot** be used for LED.

### ESP32-C3 Super Mini Note

The ESP32-C3 Super Mini has an **active-low onboard LED** (LOW = on, HIGH = off). If you are using this board, change this line in `Sterzo-ESP32-Magnetic-Steering.ino`:
```cpp
#define LED_ACTIVE_LOW true  // Set to true for ESP32-C3 onboard LED
```
This inverts the LED logic so both the built-in and external LEDs work correctly.

### Alternative Pins (Advanced)

If default pins are already in use, you can use these alternatives:
- GPIO 5, 12, 13, 14, 15, 16, 17, 18, 19, 22, 23, 25, 26, 27, 32, 33

**To change LED pin:**
Edit in `Sterzo-ESP32-Magnetic-Steering.ino`:
```cpp
#define EXTERNAL_LED_PIN 2  // Change to your desired GPIO number
```

**To change button pin:**
Edit in `Sterzo-ESP32-Magnetic-Steering.ino`:
```cpp
#define CENTER_BUTTON_PIN 4  // Change to your desired GPIO number
```

**To change I2C pins:**
Edit in `Sterzo-ESP32-Magnetic-Steering.ino`:
```cpp
#define I2C_SDA_PIN 21  // Change to your desired GPIO number
#define I2C_SCL_PIN 20  // Change to your desired GPIO number
```

**Don't use:** GPIO 20, 21 (I2C), GPIO 0, 1, 3 (boot/serial)

## Troubleshooting

### LED doesn't light up
- Check polarity (long leg to GPIO 2)
- Check resistor is connected
- Check LED is working (test with battery)
- Verify GPIO 2 connection

### LED is very dim
- Resistor value too high - try 150Ω instead of 220Ω
- LED voltage drop mismatch - try different LED

### LED is too bright or gets hot
- Resistor value too low - must use at least 150Ω
- No resistor - **NEVER** connect LED directly to GPIO!

### AS5600 not detected
- Check VCC is connected to 3.3V (NOT 5V!)
- Check SDA→GPIO21 and SCL→GPIO20 (not swapped)
- Check I2C address (should be 0x36)
- Try different jumper wires

### "Magnet too weak" or "Magnet too strong"
- Adjust distance between magnet and sensor
- Optimal gap: 1-3mm
- Magnet must be centered over sensor

### Recenter button doesn't work
- Check button is connected between GPIO 4 and GND
- Verify button works (use multimeter continuity test)
- Try a different GPIO pin and update code
- Check Serial Monitor for "Recentered!" message when pressed

## Physical Assembly

### Magnet Placement

The 6mm magnet should be:
1. **Centered** on the rotation axis
2. **2-3mm above** the AS5600 sensor chip
3. **Rotating** with the wheel/shaft
4. **Flat side parallel** to sensor surface

```
  [Rotating Part]
        |
    [Magnet] ← 6mm disc, centered
        ↕ 2-3mm gap
    [AS5600] ← Stationary, in base
        |
     [Base]
```

### LED Mounting

The 3mm LED fits into the 3.2mm hole in the front of the base:
1. Insert LED from inside
2. Route wires to ESP32
3. LED should be flush with or slightly recessed in hole
4. Secure with hot glue if needed

## Wiring Tips

1. **Use different colored wires** for easy identification:
   - Red = Power (3.3V)
   - Black = Ground
   - Yellow/Green = SDA
   - Blue/Orange = SCL

2. **Keep wires short** to reduce noise and clutter

3. **Route wires neatly** along edges to avoid pinching

4. **Label connections** with tape if using same-colored wires

5. **Test continuity** with multimeter before powering on

6. **Take photos** of your wiring before closing the case

## Safety Notes

⚠️ **Important:**
- AS5600 is a **3.3V device** - connecting to 5V may damage it
- Always use a resistor with LED - direct connection can damage ESP32
- Double-check polarity before powering on
- Disconnect power before making wiring changes

## Next Steps

After wiring is complete:
1. Upload `Sterzo-ESP32-Magnetic-Steering.ino` to ESP32
2. Open Serial Monitor at 115200 baud
3. Verify sensor detection
4. Test LED blinking
5. Place magnet and test rotation
6. Connect to Zwift and enjoy!

## Questions?

If you encounter issues, check Serial Monitor output at 115200 baud for diagnostic messages.

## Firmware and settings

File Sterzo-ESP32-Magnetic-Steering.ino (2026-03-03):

/*
 * Hook up an AS5600 magnetic rotary position sensor to ESP32 via I2C
 * AS5600 connections: SDA to GPIO 21, SCL to GPIO 20 (compatible with ESP32 Mini)
 * Place magnet on rotating shaft - sensor reads angle from 0-360°
 * Standard settings for ESP32 are used for compile & download
 * The steering angle is mapped from sensor rotation and notified to Zwift
 * The steering angle is notified to the BLE client (Zwift) every second, and then reset.

 * char 30  : angle notifications
 * char 31  : ZWIFT -> STERZO
 * char 32 : STERZO -> ZWIFT
 */

#include <BLEDevice.h>
#include <BLEUtils.h>
#include <BLEServer.h>
#include <BLE2902.h>
#include <Wire.h>
#include <AS5600.h>

// Pin definitions
#define EXTERNAL_LED_PIN 2   // GPIO 2 for external status LED
#define CENTER_BUTTON_PIN 4  // GPIO 4 for recenter button (connect button between pin and GND)
#define I2C_SDA_PIN 21       // GPIO 21 for I2C SDA (AS5600 data)
#define I2C_SCL_PIN 20       // GPIO 20 for I2C SCL (AS5600 clock) - compatible with ESP32 Mini

// LED configuration
#define LED_ACTIVE_LOW false // Set to true for ESP32-C3 onboard LED (inverts HIGH/LOW logic)

// Helper macro for LED state (inverts if active-low)
#define LED_ON  (LED_ACTIVE_LOW ? LOW : HIGH)
#define LED_OFF (LED_ACTIVE_LOW ? HIGH : LOW)

// Device configuration
#define BLE_DEVICE_NAME "ESP32 Steering"  // Bluetooth device name shown to apps

// Steering configuration
#define STEERING_DEAD_ZONE 1.0      // Degrees from center that count as "straight"
#define STEERING_SENSITIVITY 768.0  // Raw sensor units for full steering range
                                    // Lower = more sensitive, Higher = less sensitive
                                    // 512 = ~45° physical rotation for full ±40° steering
                                    // 700 = ~62° physical rotation for full ±40° steering
                                    // 1024 = ~90° physical rotation for full ±40° steering
#define STEERING_UPDATE_MS 60       // Milliseconds between BLE updates
                                    // 1000 = 1 update/sec (laggy)
                                    // 100 = 10 updates/sec (responsive)
                                    // 50 = 20 updates/sec (very responsive)

// Noise filtering configuration
#define SMOOTHING_ALPHA 0.25        // EMA smoothing factor (0.0-1.0)
                                    // Lower = smoother but more lag (e.g. 0.1)
                                    // Higher = more responsive but less filtering (e.g. 0.5)
                                    // 0.25 is a good starting point for most setups
#define SPIKE_REJECT_THRESHOLD 150  // Raw sensor units — readings that jump more than this
                                    // from the smoothed value in one sample are discarded
                                    // as noise spikes. 150 ≈ ~13° of physical rotation.

#define STERZO_SERVICE_UUID "347b0001-7635-408b-8918-8ff3949ce592"
//#define CHAR12_UUID         "347b0012-7635-408b-8918-8ff3949ce592" // not needed for Zwift
//#define CHAR13_UUID         "347b0013-7635-408b-8918-8ff3949ce592" // not needed for Zwift
#define CHAR14_UUID         "347b0014-7635-408b-8918-8ff3949ce592"
//#define CHAR19_UUID         "347b0019-7635-408b-8918-8ff3949ce592" // not needed for Zwift
#define CHAR30_UUID         "347b0030-7635-408b-8918-8ff3949ce592"
#define CHAR31_UUID         "347b0031-7635-408b-8918-8ff3949ce592"
#define CHAR32_UUID         "347b0032-7635-408b-8918-8ff3949ce592"

BLEServer *pServer;
BLEService *pSvcSterzo;
BLECharacteristic *pChar14;
BLECharacteristic *pChar30;
BLECharacteristic *pChar31;
BLECharacteristic *pChar32;
BLE2902 *p2902Char14;
BLE2902 *p2902Char30;
BLE2902 *p2902Char32;

bool deviceConnected = false;
bool challengeOK = false;
bool ind32On = false;
float steeringAngle = 0.0;

AS5600 as5600;
uint16_t centerPosition = 0;  // Center position calibration value
bool sensorReady = false;
float smoothedRawAngle = 0.0;  // EMA-filtered raw angle value
bool smoothingInitialized = false;

// Error codes for LED indication
// 0 = No error
// 1 = Sensor not found (3 fast flashes)
// 2 = Magnet not detected (4 fast flashes)
uint8_t errorCode = 0;

static uint32_t rotate_left32 (uint32_t value, uint32_t count) {
    const uint32_t mask = (CHAR_BIT * sizeof (value)) - 1;
    count &= mask;
    return (value << count) | (value >> (-count & mask));
}

static uint32_t hashed(uint64_t seed) {
    uint32_t ret = (seed + 0x16fa5717);
    uint64_t rax = seed * 0xba2e8ba3;
    uint64_t eax = (rax >> 35) * 0xb;
    uint64_t ecx = seed - eax;
    uint32_t edx = rotate_left32(seed, ecx & 0x0F);
    ret ^= edx;
    return ret;
}

static void bleNotifySteeringAngle() {
  // steeringAngle = float cast in 4 bytes
  if (1 /*char30.subscribed()*/) { //-> dit bestaat precies niet voor esp32??
    pChar30->setValue((uint8_t *)&steeringAngle,4);
    pChar30->notify();
    Serial.print("ntf angle ");Serial.println(steeringAngle);
    steeringAngle = 0.0;
  }
}

class MyServerCallbacks: public BLEServerCallbacks {
    void onConnect(BLEServer* pServer) {
      deviceConnected = true;
      Serial.println("a device connected!");
      // Restart advertising so additional clients (e.g. the Python overlay) can also connect
      BLEDevice::startAdvertising();
    };

    void onDisconnect(BLEServer* pServer) {
      deviceConnected = false;
      Serial.println("lost connection!");
    }
};

// if Zwift writes 0x310, we send a challenge on char32
class char31Callbacks: public BLECharacteristicCallbacks {
  void onWrite(BLECharacteristic* pCharacteristic) {
    String val = pCharacteristic->getValue();
    Serial.print("char31EventHandler : ");
    for (int i=0;i<val.length();i++){
      Serial.print(val[i],HEX);
      Serial.print('-');
    }
    Serial.println();
    
    if ((val[0] == 0x03) && (val[1] == 0x10)) {
      uint8_t challenge[] = {0x03,0x10,0x12,0x34}; //<2024 {0x03,0x10,0x4a,0x89}
      Serial.println("char31EventHandler : got 0x310!");
      pChar32->setValue(challenge,4);
      pChar32->indicate();
    }
    else if ((val[0] == 0x03) && (val[1] == 0x11)) {
      unsigned char fakeData[] = {0x03,0x11,0xff, 0xff};
      Serial.println("char31EventHandler : got 0x311!");
      challengeOK = true;
      pChar32->setValue(fakeData,4);
      pChar32->indicate();
    }

		else if ((val[0] == 0x03) && (val[1] == 0x12)) {
			uint32_t seed = val[5] << 24;
			seed |= val[4] << 16;
			seed |= val[3] << 8;
			seed |= val[2];
			uint32_t password = hashed(seed);
      Serial.print("char31EventHandler : got 0x312! seed = ");Serial.println(seed,HEX);

			uint8_t response[6];
			response[0] = 0x03;
			response[1] = 0x12;
			response[5] = (password & 0xFF000000 ) >> 24;
			response[4] = (password & 0x00FF0000 ) >> 16;
			response[3] = (password & 0x0000FF00 ) >> 8;
			response[2] = (password & 0x000000FF );
      pChar32->setValue(response,6);
      pChar32->indicate();

		} 
    else if ((val[0] == 0x03) && (val[1] == 0x13)) {
      Serial.println("char31EventHandler : got 0x313!");
			uint8_t response[3];
			response[0] = 0x03;
			response[1] = 0x13;
			response[2] = 0xFF;
      pChar32->setValue(response,3);
      pChar32->indicate();
      challengeOK = true; // BLE_CUS_START_SENDING_STEERING_DATA
    }
  } // onWrite

  void onRead(BLECharacteristic* pCharacteristic) {
    Serial.println("char31EventHandler onRead, doing nothing!");
  }
}; // char31Callbacks

// dummy for test to see if zwift comes here
class char32Callbacks: public BLECharacteristicCallbacks {
  void onWrite(BLECharacteristic* pCharacteristic) {
    Serial.println("char32EventHandler onWrite, doing nothing!");
  }

  void onRead(BLECharacteristic* pCharacteristic) {
    Serial.println("char32EventHandler onRead, doing nothing!");
  }
}; // char32Callbacks

class char32Desc2902Callbacks:public BLEDescriptorCallbacks {
  void onWrite(BLEDescriptor* pDescriptor) {
    uint8_t *value = pDescriptor->getValue();
    //size_t descLength = Descriptor->getLength();
    Serial.print("char32 desc 2902 written : ");Serial.println(value[0]);
    ind32On = true;
  }
};

void setup() {
  Serial.begin(115200);
  Serial.print("Starting ");
  Serial.print(BLE_DEVICE_NAME);
  Serial.println(" with AS5600!");

  // Initialize LEDs
  pinMode(LED_BUILTIN, OUTPUT);
  pinMode(EXTERNAL_LED_PIN, OUTPUT);
  digitalWrite(LED_BUILTIN, LED_ON);
  digitalWrite(EXTERNAL_LED_PIN, LED_ON);  // Turn on external LED during startup

  // Initialize recenter button (uses internal pullup, button connects to GND)
  pinMode(CENTER_BUTTON_PIN, INPUT_PULLUP);

  // Initialize I2C for AS5600 with explicit pins (compatible with ESP32 Mini)
  Wire.begin(I2C_SDA_PIN, I2C_SCL_PIN);
  Serial.println("I2C initialized");

  // Try initialization without direction pin first
  as5600.begin();
  as5600.setDirection(AS5600_CLOCK_WISE);  // Set rotation direction
  delay(100);  // Give sensor time to initialize

  Serial.print("Checking AS5600 connection... ");

  // Check if AS5600 is connected
  if (as5600.isConnected()) {
    Serial.println("AS5600 sensor detected!");
    sensorReady = true;

    // Check magnet status register (informational only)
    int magnetStatus = as5600.readStatus();
    Serial.print("Magnet status register: 0x");
    Serial.print(magnetStatus, HEX);
    Serial.print(" - ");
    if (magnetStatus & 0x20) Serial.print("Too strong ");
    if (magnetStatus & 0x10) Serial.print("Too weak ");
    if (magnetStatus & 0x08) Serial.print("Detected ");
    Serial.println();

    // Read initial center position for calibration
    delay(100);
    centerPosition = as5600.rawAngle();
    smoothedRawAngle = (float)centerPosition;  // Seed EMA at center to avoid startup jerk
    smoothingInitialized = true;
    Serial.print("Center position set to: ");
    Serial.println(centerPosition);

    // Practical magnet detection: check if we get valid, consistent readings
    // Take a few readings and verify they're stable (not random noise)
    delay(50);
    uint16_t reading1 = as5600.rawAngle();
    delay(50);
    uint16_t reading2 = as5600.rawAngle();
    int16_t diff = abs((int16_t)reading1 - (int16_t)reading2);

    Serial.print("Stability check: ");
    Serial.print(reading1);
    Serial.print(" vs ");
    Serial.print(reading2);
    Serial.print(" (diff: ");
    Serial.print(diff);
    Serial.println(")");

    // If readings are valid (0-4095) and stable (not jumping around wildly), magnet is OK
    if (reading1 < 4096 && reading2 < 4096 && diff < 100) {
      errorCode = 0;  // No error - sensor working properly
      Serial.println("Magnet OK - readings are stable");
    } else {
      errorCode = 2;  // Magnet issue (4 flashes)
      Serial.println("Warning: Unstable readings - check magnet position");
    }
  } else {
    Serial.println("FAILED!");
    Serial.println("AS5600 sensor not responding to isConnected() check.");
    Serial.println("Attempting to read raw angle anyway...");

    // Try to read raw angle directly even if isConnected() fails
    uint16_t testAngle = as5600.rawAngle();
    Serial.print("Raw angle reading: ");
    Serial.println(testAngle);

    if (testAngle > 0 && testAngle < 4096) {
      Serial.println("Sensor appears to be working despite isConnected() failure!");
      sensorReady = true;
      centerPosition = testAngle;
      errorCode = 0;  // If we can read angles, it's working
    } else {
      Serial.println("Sensor not responding. Check wiring and magnet placement.");
      sensorReady = false;
      errorCode = 1;  // Sensor not found (3 flashes)
    }
  }

  BLEDevice::init(BLE_DEVICE_NAME);
  pServer = BLEDevice::createServer();
  pServer->setCallbacks(new MyServerCallbacks());
  //pSvcSterzo = pServer->createService("347b0001-7635-408b-8918-8ff3949ce592");
  pSvcSterzo = pServer->createService(BLEUUID(STERZO_SERVICE_UUID));
  pChar14 = pSvcSterzo->createCharacteristic(CHAR14_UUID,BLECharacteristic::PROPERTY_NOTIFY); // 1 byte 0xFF, doet niets
  pChar30 = pSvcSterzo->createCharacteristic(CHAR30_UUID,BLECharacteristic::PROPERTY_NOTIFY); // 4 bytes steering angle
  pChar31 = pSvcSterzo->createCharacteristic(CHAR31_UUID,BLECharacteristic::PROPERTY_WRITE); // zwift writes 4 bytes
  pChar32 = pSvcSterzo->createCharacteristic(CHAR32_UUID,BLECharacteristic::PROPERTY_INDICATE); // 4 bytes challenge

  p2902Char14 = new BLE2902();
  p2902Char30 = new BLE2902();
  p2902Char30->setNotifications(true);
  p2902Char32 = new BLE2902();
  p2902Char32->setCallbacks(new char32Desc2902Callbacks());
  pChar14->addDescriptor(p2902Char14);
  pChar30->addDescriptor(p2902Char30);
  pChar32->addDescriptor(p2902Char32);

  // initial values
  uint8_t defaultValue[4] = {0x0,0x0,0x0,0x0};
  pChar30->setValue(defaultValue,4); // default angle = 0
  defaultValue[0] = 0xFF; // fill other characteristics with a default 0xFF
  pChar14->setValue(defaultValue,1);
  pChar31->setValue(defaultValue,4);
  uint8_t challenge[] = {0x03,0x10,0x12, 0x34}; //<2024 {0x03,0x10,0x4a, 0x89};
  pChar32->setValue(challenge,4);

  pChar31->setCallbacks(new char31Callbacks());
  pChar32->setCallbacks(new char32Callbacks()); // 2024 for test only TODO REMOVE

  pSvcSterzo->start();
  // BLEAdvertising *pAdvertising = pServer->getAdvertising();  // this still is working for backward compatibility
  BLEAdvertising *pAdvertising = BLEDevice::getAdvertising();
  pAdvertising->addServiceUUID(STERZO_SERVICE_UUID);
  pAdvertising->setScanResponse(true);
  pAdvertising->setMinPreferred(0x06);  // functions that help with iPhone connections issue
  pAdvertising->setMinPreferred(0x12);
  BLEDevice::startAdvertising();
  Serial.print(BLE_DEVICE_NAME);
  Serial.println(" ready!");

  // Print error code status
  if (errorCode == 0) {
    Serial.println("Status: OK - Sensor and magnet detected");
    Serial.println("LED: Slow blink = waiting for Zwift, Fast blink = connected");
  } else if (errorCode == 1) {
    Serial.println("ERROR: Sensor not found!");
    Serial.println("LED: 3 fast flashes = sensor not found");
  } else if (errorCode == 2) {
    Serial.println("ERROR: Magnet not detected!");
    Serial.println("LED: 4 fast flashes = magnet not detected");
  }
}

uint32_t bleNotifyMillis;
uint32_t serialPrintMillis;
uint32_t challengeMillis;
uint32_t blinkMillis;
uint32_t errorFlashMillis;
uint32_t lastRecenterMillis = 0;
uint8_t errorFlashCount = 0;
bool errorFlashState = false;
bool inErrorFlashSequence = false;

void loop() {

  uint32_t blinkInterval;

  // LED status indication:
  // - No error: Slow blink (1000ms) = Not connected, Fast blink (500ms) = Connected
  // - Error code 1 (sensor not found): 3 fast flashes, then pause
  // - Error code 2 (magnet not detected): 4 fast flashes, then pause

  if (errorCode > 0) {
    // Error flash pattern
    uint8_t flashCount = (errorCode == 1) ? 3 : 4;  // 3 flashes for sensor, 4 for magnet

    if (!inErrorFlashSequence) {
      // Start a new flash sequence
      inErrorFlashSequence = true;
      errorFlashCount = 0;
      errorFlashState = false;
      errorFlashMillis = millis();
    }

    uint32_t elapsed = millis() - errorFlashMillis;

    if (errorFlashCount < flashCount * 2) {
      // During flash sequence (100ms on, 100ms off per flash)
      if (elapsed > 100) {
        errorFlashState = !errorFlashState;
        digitalWrite(LED_BUILTIN, errorFlashState ? LED_ON : LED_OFF);
        digitalWrite(EXTERNAL_LED_PIN, errorFlashState ? LED_ON : LED_OFF);
        errorFlashMillis = millis();
        errorFlashCount++;
      }
    } else {
      // Pause after flashes (1500ms)
      digitalWrite(LED_BUILTIN, LED_OFF);
      digitalWrite(EXTERNAL_LED_PIN, LED_OFF);
      if (elapsed > 1500) {
        inErrorFlashSequence = false;  // Restart sequence
      }
    }
  } else {
    // Normal operation - blink to show connection status
    // Slow blink (1000ms) = Not connected to Zwift
    // Fast blink (500ms) = Connected to Zwift
    blinkInterval = 1000;
    if (deviceConnected) {
      blinkInterval = 500;
    }
    if ((millis() - blinkMillis) > blinkInterval) {
      static bool blinkState = false;
      blinkState = !blinkState;
      digitalWrite(LED_BUILTIN, blinkState ? LED_ON : LED_OFF);
      digitalWrite(EXTERNAL_LED_PIN, blinkState ? LED_ON : LED_OFF);
      blinkMillis = millis();
    }
  }

  // Check recenter button (button pressed = LOW due to INPUT_PULLUP)
  if (sensorReady && digitalRead(CENTER_BUTTON_PIN) == LOW) {
    // Debounce: only allow recenter every 500ms
    if (millis() - lastRecenterMillis > 500) {
      lastRecenterMillis = millis();

      // Set current position as new center
      centerPosition = as5600.rawAngle();
      smoothedRawAngle = (float)centerPosition;  // Reseed EMA so there's no offset drift after recenter
      Serial.print("Recentered! New center position: ");
      Serial.println(centerPosition);

      // Visual feedback: 2 quick flashes
      for (int i = 0; i < 2; i++) {
        digitalWrite(LED_BUILTIN, LED_ON);
        digitalWrite(EXTERNAL_LED_PIN, LED_ON);
        delay(100);
        digitalWrite(LED_BUILTIN, LED_OFF);
        digitalWrite(EXTERNAL_LED_PIN, LED_OFF);
        delay(100);
      }
    }
  }

  // Read AS5600 sensor and calculate steering angle
  if (sensorReady) {
    uint16_t rawAngle = as5600.rawAngle();  // 0-4095 (12-bit)

    if (!smoothingInitialized) {
      // Seed the EMA with the first real reading so it doesn't start at 0
      smoothedRawAngle = (float)rawAngle;
      smoothingInitialized = true;
    } else {
      // Spike rejection: if this reading jumps too far from the smoothed value,
      // it's almost certainly vibration noise — discard it and keep the last good value.
      // We compare using shortest-path wraparound arithmetic.
      float diff = (float)rawAngle - smoothedRawAngle;
      if (diff > 2048.0f) diff -= 4096.0f;
      if (diff < -2048.0f) diff += 4096.0f;

      if (abs(diff) < SPIKE_REJECT_THRESHOLD) {
        // Normal reading — apply EMA smoothing
        smoothedRawAngle += SMOOTHING_ALPHA * diff;
        // Keep smoothedRawAngle in [0, 4096) range
        if (smoothedRawAngle < 0.0f) smoothedRawAngle += 4096.0f;
        if (smoothedRawAngle >= 4096.0f) smoothedRawAngle -= 4096.0f;
      }
      // If spike detected, smoothedRawAngle is unchanged (sample discarded)
    }

    // Calculate angle difference from center position using smoothed value
    float angleDiff = smoothedRawAngle - (float)centerPosition;

    // Handle wraparound (e.g., if center is at 4000 and smoothed is at 100)
    if (angleDiff > 2048.0f) angleDiff -= 4096.0f;
    if (angleDiff < -2048.0f) angleDiff += 4096.0f;

    // Map angle difference to steering range (-40 to +40 degrees)
    float mappedAngle = angleDiff / STEERING_SENSITIVITY * 40.0f;

    // Limit to Zwift steering range
    if (mappedAngle > 40.0f) mappedAngle = 40.0f;
    if (mappedAngle < -40.0f) mappedAngle = -40.0f;

    // Apply dead zone - angles within ±STEERING_DEAD_ZONE are treated as straight
    if (mappedAngle > -STEERING_DEAD_ZONE && mappedAngle < STEERING_DEAD_ZONE) {
      mappedAngle = 0.0f;
    }

    steeringAngle = mappedAngle;
  }
  // steering angle will be reset after each BLE-notify

  /*
  // alt : manually activate char32 indications, not waiting for zwift to do this
  if (deviceConnected && (!p2902Char32->getIndications())) {
    Serial.println("manually enabling char32 indications");
    p2902Char32->setIndications(true);
    challengeMillis = millis();
    ind32On = true;
  }
  */

  // if Zwift subscribes to the notifications, we send the initial challenge on char32
  // 2024 : put in a retry every 5 seconds until challengeOK, but zwift doesn't seem to send anything on char 31
  if (deviceConnected && ind32On && !challengeOK && ((millis() - challengeMillis) > 5000)) { 
    challengeMillis = millis();
    Serial.println("sending initial challenge on char32");
    uint8_t challenge[] = {0x03,0x10,0x12,0x34}; //<2024 {0x03,0x10,0x4a, 0x89};
    pChar32->setValue(challenge,4);
    pChar32->indicate();
  }

  // challengeOK remains false because zwift doesn't seem to send anything on char 31
  // so for workaround we start sending steering angles as soon as zwift connects, and strangely enough that works
  //if (deviceConnected && challengeOK) { 
  // Always print angle to serial so the Python overlay can read it over USB
  // regardless of whether a BLE client (GTBikeV) is connected
  if (sensorReady && (millis() - serialPrintMillis > STEERING_UPDATE_MS)) {
    Serial.print("ntf angle "); Serial.println(steeringAngle);
    serialPrintMillis = millis();
  }

  if (deviceConnected) {
    if (millis() - bleNotifyMillis > STEERING_UPDATE_MS) {
      bleNotifySteeringAngle ();
      bleNotifyMillis = millis();
    }
  }
} // loop

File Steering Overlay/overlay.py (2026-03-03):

"""
Steering Overlay — live steering angle display for GTBikeV.

The connection mode is chosen from the dropdown in the overlay window:
  • BLE           — Bluetooth direct (use when not in-game)
  • /dev/cu.xxx   — USB serial port  (use while GTBikeV is running)

Usage:
    python overlay.py              # launch overlay
    python overlay.py --list-ports # list available serial ports and exit
    python overlay.py --baud 115200  # override baud rate (default: 115200)
"""

import argparse
import asyncio
import math
import queue
import struct
import threading
import time
import tkinter as tk

from bleak import BleakClient, BleakScanner

# ── BLE constants ─────────────────────────────────────────────────────────────
SERVICE_UUID = "347b0001-7635-408b-8918-8ff3949ce592"
CHAR30_UUID  = "347b0030-7635-408b-8918-8ff3949ce592"
DEVICE_NAME  = "ESP32 Steering"

RECONNECT_DELAY = 3   # seconds between reconnect attempts

# ── Shared state ──────────────────────────────────────────────────────────────
angle_queue: queue.Queue = queue.Queue(maxsize=10)
stop_event        = threading.Event()   # set to shut down the app

# connection_mode[0] is either "ble" or a serial port device path.
# mode_change_event is set whenever connection_mode[0] is updated so the
# supervisor thread wakes up and reconnects with the new mode.
connection_mode   = ["ble"]
mode_change_event = threading.Event()


# ── Serial port helpers ───────────────────────────────────────────────────────

def _list_serial_ports():
    """Return [(device, label), ...] for non-trivial serial ports."""
    try:
        import serial.tools.list_ports
    except ImportError:
        return []

    skip = ("debug-console", "bluetooth-incoming")
    result = []
    for p in serial.tools.list_ports.comports():
        if any(s in p.device.lower() for s in skip):
            continue
        desc = p.description or ""
        label = f"{p.device}  —  {desc}" if desc and desc.lower() != "n/a" else p.device
        result.append((p.device, label))
    return result



# ── Supervisor thread ─────────────────────────────────────────────────────────

def supervisor_thread(baud: int):
    """Launch BLE or serial sub-loop based on connection_mode[0].
    Re-launches automatically whenever the user changes the dropdown."""
    while not stop_event.is_set():
        mode_change_event.clear()
        mode = connection_mode[0]
        angle_queue.put(("status", "disconnected"))

        if mode == "ble":
            asyncio.run(_ble_main())
        else:
            _serial_loop(mode, baud)

        # After sub-loop exits (mode change, disconnect, or stop):
        if not stop_event.is_set() and not mode_change_event.is_set():
            angle_queue.put(("status", "disconnected"))
            time.sleep(RECONNECT_DELAY)


# ── BLE sub-loop ──────────────────────────────────────────────────────────────

async def _ble_main():
    while not stop_event.is_set() and not mode_change_event.is_set():
        angle_queue.put(("status", "scanning"))
        device = await _scan()
        if device is None:
            await asyncio.sleep(RECONNECT_DELAY)
            continue

        angle_queue.put(("status", "connecting"))
        try:
            async with BleakClient(device) as client:
                angle_queue.put(("status", "connected"))

                def _notify(_, data: bytearray):
                    if len(data) >= 4:
                        angle = struct.unpack("<f", data[:4])[0]
                        if angle_queue.full():
                            try:
                                angle_queue.get_nowait()
                            except queue.Empty:
                                pass
                        angle_queue.put(("angle", angle))

                await client.start_notify(CHAR30_UUID, _notify)

                while (client.is_connected
                       and not stop_event.is_set()
                       and not mode_change_event.is_set()):
                    await asyncio.sleep(0.5)

                await client.stop_notify(CHAR30_UUID)
        except Exception:
            pass

        if not stop_event.is_set() and not mode_change_event.is_set():
            angle_queue.put(("status", "disconnected"))
            await asyncio.sleep(RECONNECT_DELAY)


async def _scan():
    try:
        return await BleakScanner.find_device_by_filter(
            lambda d, adv: (
                SERVICE_UUID.lower() in [s.lower() for s in (adv.service_uuids or [])]
                or (d.name and DEVICE_NAME.lower() in d.name.lower())
            ),
            timeout=10.0,
        )
    except Exception:
        return None


# ── Serial sub-loop ───────────────────────────────────────────────────────────

def _serial_loop(port: str, baud: int):
    import serial as pyserial

    while not stop_event.is_set() and not mode_change_event.is_set():
        angle_queue.put(("status", "connecting"))
        try:
            with pyserial.Serial(port, baud, timeout=1) as ser:
                angle_queue.put(("status", "connected"))
                while not stop_event.is_set() and not mode_change_event.is_set():
                    try:
                        line = ser.readline().decode("utf-8", errors="ignore").strip()
                    except Exception:
                        break
                    if line.startswith("ntf angle "):
                        try:
                            angle = float(line[len("ntf angle "):])
                            if angle_queue.full():
                                try:
                                    angle_queue.get_nowait()
                                except queue.Empty:
                                    pass
                            angle_queue.put(("angle", angle))
                        except ValueError:
                            pass
        except Exception:
            pass

        if not stop_event.is_set() and not mode_change_event.is_set():
            angle_queue.put(("status", "disconnected"))
            time.sleep(RECONNECT_DELAY)


# ── Tkinter UI ────────────────────────────────────────────────────────────────

ANGLE_MIN      = -40.0
ANGLE_MAX      =  40.0

# Arc (steering wheel) geometry
ARC_W          = 260          # canvas width
ARC_H          = 110          # canvas height
ARC_CX         = ARC_W // 2  # arc pivot x (centre)
ARC_CY         = ARC_H - 2   # arc pivot y (near bottom edge)
ARC_R          = 85           # track radius
ARC_NEEDLE_R   = 76           # needle tip radius (inside the track)
ARC_HALF_SPAN  = 65           # visual degrees from centre to each end
ARC_TRACK_W    = 6            # track stroke width

BG          = "#1a1a1a"
FG          = "#ffffff"
TRACK_COLOR = "#444444"
INDICATOR   = "#00aaff"
GREEN       = "#00cc44"
YELLOW      = "#ffcc00"
RED         = "#ff4444"
BADGE_BLE   = "#1a4a6e"
BADGE_USB   = "#3a2a6e"
BTN_FG      = "#888888"

BLE_LABEL   = "BLE  —  Bluetooth (testing only)"
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

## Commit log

2026-01-19 Initial Commit
    Moving from previous forked repo
    [Steering Controller.scad]
2026-01-19 update SCAD to appropriate defaults
    [Steering Controller.scad]
2026-01-19 Update Steering Controller.scad
    [Steering Controller.scad]
2026-01-19 Documentation update and pre-rendered models
    [Fit Test - 608 Bearing.stl, Fit Test - AS5600 Sensor.stl, Steering Controller Base.stl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]
2026-01-19 Move rendered pieces to subfolder
    [Fit Test - 608 Bearing.stl, Fit Test - AS5600 Sensor.stl, Steering Controller Base.stl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]
2026-01-20 Update model issues, change default pins for I2C
    [Steering Controller Base.stl, Steering Controller Door.stl, Steering Controller.scad]
2026-02-12 updated version with completed OpenSCAD model
    Updated version, configuring settings to be compatible with ESP32 Super Mini boards.
    Added an Open SCAD model that is customizable to use for the enclosure.
    [Steering Controller PETG Feet.stl, Steering Controller.scad]
2026-03-03 Rename main sketch and update docs to match project name
    Renamed ESP32Sterzo.ino to Sterzo-ESP32-Magnetic-Steering.ino to match
    the project folder name (required by Arduino IDE). Updated all references
    in README.md, LED_QUICK_REFERENCE.md, and WIRING_GUIDE.md accordingly.
    Also adds EMA smoothing and spike rejection to reduce erratic steering
    from vibration noise, and seeds the smoothed angle at startup/recenter.
    [Sterzo-ESP32-Magnetic-Steering.ino]
2026-03-03 Add Steering Overlay app for live BLE angle display
    Adds a lightweight Python overlay that connects to the ESP32 Sterzo
    device via BLE and shows a floating always-on-top window with a live
    steering bar and numeric angle readout. Useful for tuning sensitivity
    while riding in GTBikeV.
2026-03-03 Add USB serial mode to Steering Overlay; fix BLE multi-client advertising
    - overlay.py: add --mode serial flag for reading angle from USB serial
    port while GTBikeV holds the BLE connection; auto-detects ESP32 port
    (CP210x, CH340, FTDI, JTAG/usbmodem); BLE mode unchanged as default
    - overlay.py: add --list-ports flag, mode badge (BLE/USB) in title bar
    - firmware: restart BLE advertising in onConnect so multiple clients
    (e.g. game + overlay) can connect simultaneously
    [Sterzo-ESP32-Magnetic-Steering.ino, overlay.py]
2026-03-03 Add in-window mode/port picker; fix serial output for standalone use
    Overlay:
    - Replace --mode/--port CLI args with an in-window dropdown listing
    BLE and all available USB serial ports; mode switches live at runtime
    - Add ↺ refresh button to rescan ports without restarting
    - Badge (BLE/USB) in title updates when mode changes
    - Single supervisor thread hot-swaps between BLE and serial sub-loops
    when user changes the dropdown selection
    Firmware:
    - Print angle to serial unconditionally (not just when BLE client is
    connected) so serial overlay works without GTBikeV running
    [Sterzo-ESP32-Magnetic-Steering.ino, overlay.py]
2026-03-03 Replace steering bar with arc indicator; fix dropdown text colour
    - Draw a curved arc (steering wheel style) spanning ±40° with a needle,
    coloured fill arc from centre to current angle, pivot dot, and labels
    - Improve dropdown text legibility (#aaaaaa → #dddddd)
    - Expand window height to accommodate the taller arc canvas
    [overlay.py]
2026-03-03 Document Steering Overlay app (closes #1)
    Add full Steering Overlay section to README covering:
    - BLE vs USB serial modes and when to use each
    - pip install prerequisites (bleak + pyserial)
    - How to run (no CLI flags needed; dropdown in UI)
    - UI walkthrough: arc indicator, fill arc, needle, angle readout,
    status dot, Via: dropdown, refresh and close buttons
    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
